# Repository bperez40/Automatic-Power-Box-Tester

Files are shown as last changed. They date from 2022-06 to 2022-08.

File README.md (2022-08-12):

# Automatic Power Box Tester
Summer 2022 ITW Vulcan Project

## Firmware Guide
 This guide assumes you're running Windows, however, you can easily do all this on other platforms, but some of the steps will vary slightly, and you probably won't be using anything with a batch script on another platform (unless you really want to).

### Cloning Repo (required)
If you don't have git installed, go ahead and download it from here: https://git-scm.com/
Then, in a command-line shell (On Windows, Command Prompt and PowerShell are installed by default), navigate to wherever you want to store the project and then run:
git clone https://github.com/bperez40/Arduino-Power-Box-Tester

The repository is layed out as follows
```
Automatic-Power-Box-Tester
├───lib
│   ├───Adafruit-GFX-Library
│   ├───Adafruit_BusIO
│   ├───Adafruit_RA8875
│   ├───iodefs
│   ├───PBTCheck
│   ├───PBTGraphics
│   └───PWM
├───main
├───tests
│   ├───ADC_test
│   └───PWM_Out
└───util
    ├───Hardware Design Files
    │   ├───AutoPowerBoxTesterv1.0
    │   │   └───GerberFiles
    │   ├───AutoPowerBoxTesterv1.1
    │   │   └───GerberFiles
    │   └───SparkWireInterfacev1.0
    │       └───GerberFiles
    ├───scripts
    └───images
```
Opening it up, you'll be on the root of the repository.
- main stores the main program
- lib has all the required external and custom libraries for the project
- tests has some basic tests mostly used for debugging and not much else
- util has images used in the readme as well as all the hardware design files for the PCBs

Go ahead and run the update.bat script. This initializes all the submodules, which have dependencies that the firmware uses. Also run this whenever you want to pull the most recent version of the firmware.

### Arduino Setup (required)
We're not quite ready to actually compile and upload firmware to the Arduino yet. We need to install a program to do so. You have a few ways to do this.

#### 1. Using Arduino CLI (recommended)
If you want to use the Arduino CLI to make your own custom configuration, start by downloading the Arduino CLI from Arduino here: https://www.arduino.cc/pro/cli

Extract it in the repository's root and rename the folder it's contained in to .arduino-cli. So, {top-of-repository}/.arduino-cli

Your new file structure will look something like this...
```
Automatic-Power-Box-Tester
├───.arduino-cli
├───lib
│   ├───Adafruit-GFX-Library
│   ├───Adafruit_BusIO
│   ├───Adafruit_RA8875
│   ├───iodefs
│   ├───PBTCheck
│   ├───PBTGraphics
│   └───PWM
├───main
├───tests
│   ├───ADC_test
│   └───PWM_Out
└───util
    ├───Hardware Design Files
    │   ├───AutoPowerBoxTesterv1.0
    │   │   └───GerberFiles
    │   ├───AutoPowerBoxTesterv1.1
    │   │   └───GerberFiles
    │   └───SparkWireInterfacev1.0
    │       └───GerberFiles
    ├───scripts
    └───images
```

The fast way to compile and upload the program is to run the CompileAndUpload.bat script in util.

If you want to compile it manually and play around the the CLI a bit, you can do the following.

To compile, run the following from your root folder:

arduino-cli.exe compile --build-path ./build --libraries ./lib -b Arduino:avr:mega main/main.ino

To compile and upload, you can instead do:

arduino-cli.exe compile --build-path ./build --libraries ./lib -b Arduino:avr:mega -p COM4 -u main/main.ino

Replacing COM4 with whatever your Arduino is actually using. You can figure that out by running:

arduino-cli.exe board list

This is also how you can figure out an Arduino's FQBN.

#### 2. Using Arduino IDE
I haven't set this up on Arduino IDE, but I imagine this is what people are more familar with when using any Arduino platform. If you do this, you'll have to manually add the libraries using the GUI and set up the board type and COM port similar to option 2. If that's done correctly, all you have to do is press the run button and it should work fine.

### Changing the lock screen password (important, but optional)
I recognize that this is incredibly insecure, but it's highly unlikely anyone who would abuse this would come looking here to do so.

To change the lockscreen password, navigate to PBTGraphics.cpp and change the line with...

int actual_passcode[4] = {#, #, #, #}; /*!! SET PASSCODE HERE !!*/

...by setting the # to whatever you want it to be, in the order you want them to be entered. Then build and upload the project to the Arduino.

### Running Python Scripts (optional)
If you don't already have it installed, install from their website: https://www.python.org/

Once Python is installed, open a terminal. 

In the repository's root folder, run python -m venv .venv
.venv is gitignored by default, but if you want to name it something else, change the gitignore to reflect whatever you call it.

VSCode should give a prompt that it has detected a new virtual environment. Confirm the prompt.

Select the proper virtual environment interpreter by opening the command pallette and selecting it using >Python: Select Interpreter

In Windows, run the activate script to use your virtual environment. You could use the
global environment instead, but that's icky:
{wherever-venv-is}\.venv\scripts\activate

If using the debugger, you might need to activate it again in the new terminal that pops up.

If you get the message "Activate.ps1" is not digitally signed, run:
Set-ExecutionPolicy -ExecutionPolicy RemoteSigned -Scope Process

Once the virtual environment is activated, install whatever packages you want using
pip install {package-name}
If you get an error running a python script, chances are you're missing a package. Read the terminal output to see what exactly the error is.

Whenever you're done working in the virtual environment, type deactivate and you'll leave the virtual environment and return to the global environment.

### Logging Arduino output data using PuTTY (optional)
If you want to log the Arduino's output data when it's connected over USB, you can do so using PuTTY (or TeraTerm, or whatever other similar program).

First, install PuTTY from here: https://www.putty.org/

Match all the proper settings in the session tab, such as COM port, baud rate, so on so forth.

In the logging tab, set session logging to "All session output." Name the file whatever you like and configure PuTTY to store putty.log or whatever you want to call it in the util folder of the repository. When you start a session, PuTTY will then create a log in the util folder. You can run the visualizer python script to then visualize the file's output. This is useful for graphing ADC data.

If you want to start PuTTY using a terminal, run the following command:

plink.exe -load {SAVED-PROFILE}

Where the saved profile is one that you've previously set up. If plink.exe isn't found, make sure it's part of your PATH environment.

## Hardware
Hardware design files and assembly instructions can be found in util/HardwareDesignFiles.\
They include the EAGLE board and schematic files, gerber files, BOM, and pick and place for each board.\
You can also view each board on AISLER with the following links.\
[Auto Power Box Tester v1.1 (redirect)](https://aisler.net/p/JCLNWTRR)\
[Spark Wire Interface Board v1.0 (redirect)](https://aisler.net/p/PQONZLWA)\
[Auto Power Box Tester v1.0 (redirect)](https://aisler.net/p/SKLRNZQZ)

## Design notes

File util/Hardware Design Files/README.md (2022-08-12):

# Hardware Guide
Originally, the power box tester was intended to be a single board to which you attach connectors to. Were it not for the 25 kV ignition, this would be possible. However, because we could not implement a part of the circuit on either the Auto Power Box Tester PCB or on the Spark Wire Interface board due to time limitations, the setup requires slightly more complexity and care.

## Auto Power Box Tester v1.1 Assembly
Setting up the Auto Power Box Tester v1.1 is very straightforward, though it does require a bit of soldering (though every part can be done with a soldering iron alone).

If you have no prior experience with soldering, here are a few guides on how to do so.

SMD soldering: https://www.sparkfun.com/tutorials/36
Through hole soldering: https://learn.sparkfun.com/tutorials/how-to-solder-through-hole-soldering/all#res
Hot air: https://learn.sparkfun.com/tutorials/how-to-use-a-hot-air-rework-station/all

Assemble the board in its entirety. Ideally, this board would be assembled by the PCB manufacturer, so for future revisions, consider getting this assembled by the manufacturer as it is more or less in a stable position. 

The connectors are also all assembled with each connection as is with the exception of the blower motor connector, which I will elaborate on later. Each of these connectors have a Mini-Fit Jr. receptacle on one end and a Mini-Fit Jr. panel mount plug on the other end.

The Spark Wire Interface board is a supplementary board to the main board. It required major adjustments after production, so this is where the complexity comes in.

First, start by assembling the required components of the spark interface board. Adjustments were made to exclude parts of the board, so you will only need to assemble:
- J1
- R3
- R4
- D1
- Quick connect tab on the holes labeled "spark wire connect"

After those are assembled, you will also need to place a jumper wire in one location, with the solder joints being circled in this image:\
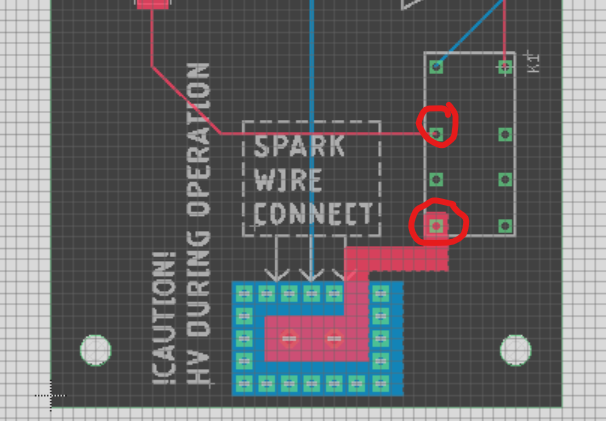
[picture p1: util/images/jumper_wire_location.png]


As a result, it will look something like this:\
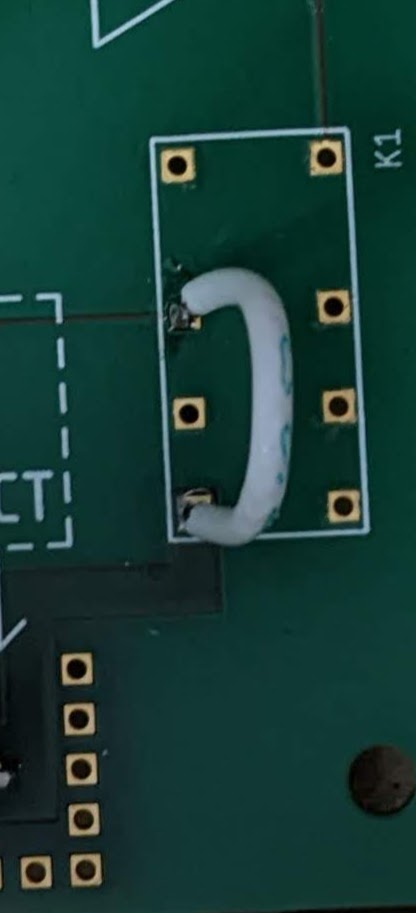
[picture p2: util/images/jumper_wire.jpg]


The idea here is we're trying to short the path that leads between the spark wire interface and the rectification circuit. Instead of that circuit being closed by a +3.3v relay (as it originally was supposed to be), it is being closed by a 120 VAC contactor. We had to change those out as the contactor could handle the higher voltage rating on its contacts (effectively, it prevented the high voltage line from arcing when in its open position due to the larger air gaps).

Now, we need to make a few connections. Terminal block for reference:\
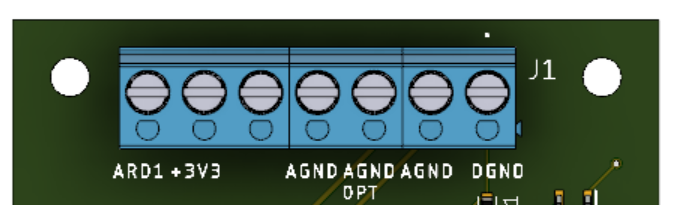
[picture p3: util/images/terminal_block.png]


Start by connecting the left most AGND to the interior of the chassis (requires a ring terminal crimp). Next, connect the right AGND to a wire nut. From that wire nut, you need to attach two more wires to two separate locations: One back to AGND OPT, and the other to one side of the contactor's coil (requires a quick connect crimp). The other side of the contactor's coil should be connected to wire 2 on the blower motor connector. That way, the contactor now has both 120 VAC and GND connected to its coil.

After the two boards are assembled properly, you'll need to make connections to the breadboard and contactor. Usually, the breadboard would be integrated onto the spark interface board, but since there wasn't enough time remaining in the internship to do so, we had to settle for this.

The breadboard is a corrected circuit of what the spark interface board should have been, and it requires the following
- NPN transistor (like the MPSA06): 1
- 270 ohm resistor: 1
- 3700 ohm resistor: 2
- [J104D2C3VDC.15S or equivalent 3.3v relay](https://www.digikey.com/en/products/detail/cit-relay-and-switch/J104D2C3VDC-15S/12502634)
- [CPC1976Y, AQY212GHAX, or something similar](https://www.digikey.com/en/products/detail/ixys-integrated-circuits-division/CPC1976Y/1277138)

Using these, you need to build the following circuit. Pay heed to the comments:\
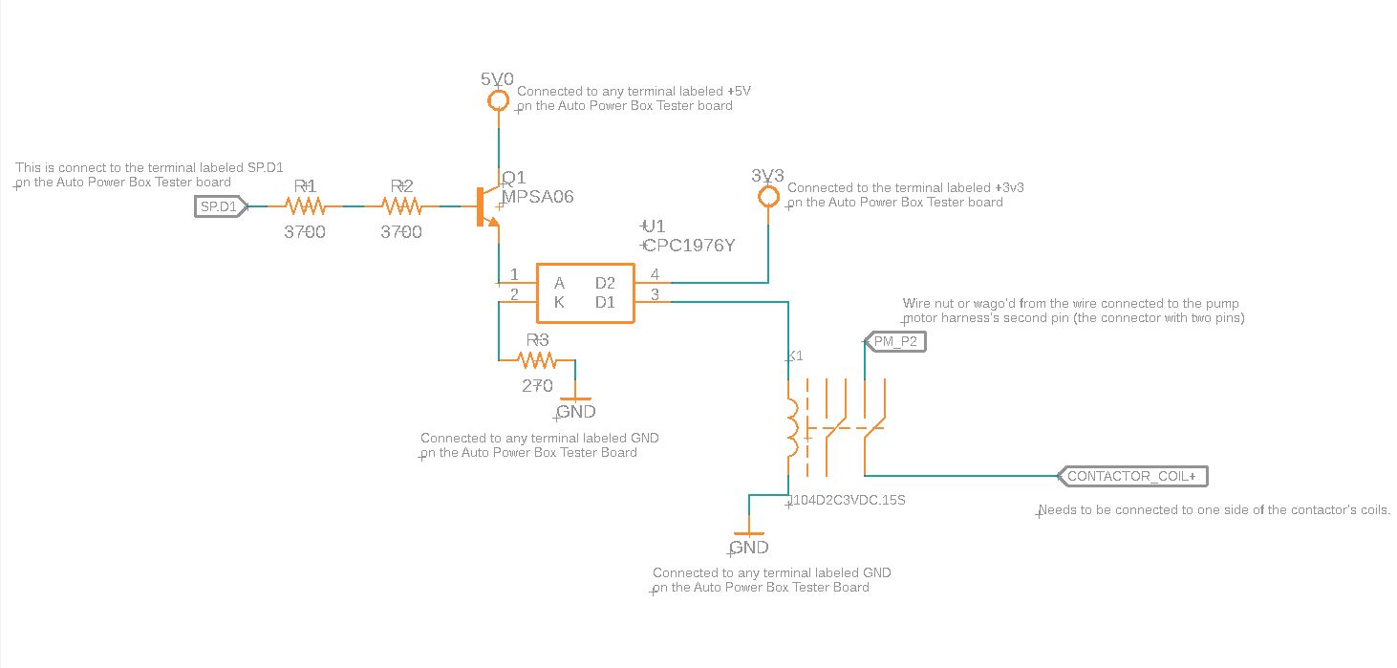
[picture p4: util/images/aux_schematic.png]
Schematic


To finish these connections, we need to connect the rest of the contactor's connections. We've already attached the necessary wires to the coil ends, but we need to set up the spark wire to connect to the terminal. One side of a terminal should by connected directly to the power box's spark wire (usually we connect the spark wire to a QC terminal on the workbench and have another wire leading into the Auto Power Box Tester's chassis, where it then connects to one of the contactor's terminal). The other side of that terminal should be connected to the quick connect labeled "SPARK WIRE CONNECT" on the spark wire interface board. After that, the device should be fully electrically assembled. You know this is done incorrectly if the device is never able to rectify the signal (no path to ground) or if there is arcing occuring between the AGND and AGND OPT traces (unequal potentials between these two signals).

Effectively, what all this was for was to allow the Arduino to be able to control when the spark wire's signal is being recitified or not. The circuit on the breadboard allows the Arduino to control a 120 VAC signal (on the pump motor connector's second wire), which in turn triggers the contactor on and off.

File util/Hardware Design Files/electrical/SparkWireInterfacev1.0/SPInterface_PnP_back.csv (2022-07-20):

R2 | 40.64 | 104.14 | 180.00 | 3300 | RESC1608X60
U2 | 49.53 | 106.68 | 90.00 | PZTA06SOT-223_ONS | SOT-223_ONS

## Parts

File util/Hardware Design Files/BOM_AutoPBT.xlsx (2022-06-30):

Description | Qty | MPN | Designator | Footprint | Additional Comments
PCB Components
1k ohm, 1/4 W, 0603, 1% | 13 | CRGP0603F1K0 | R1, R6, R8, R9, R16, R17, R18, R34, R35, R36, R37, R44, R45 | CHIP-0603(1608-METRIC)
330 ohm, 1/4 W, 0603, 1% | 7 | CRGP0603F330R | R2, R7, R10, R14, R15, R28, R33 | CHIP-0603(1608-METRIC)
3.3k ohm, 1/4 W, 0603, 1% | 7 | CRGP0603F3K3 | R3, R4, R5, R11, R12, R13, R19 | CHIP-0603(1608-METRIC)
Mini-Fit Jr. 39281023 | 1 | 39281023 | J3 | CON_39281023
Mini-Fit Jr. 39281043 | 1 | 39299046 | J6 | CON_39281043
Mini-Fit Jr. 39281063 | 2 | 39293066 | J2, J5 | CON_39281063
Mini-Fit Jr. 39281123 | 1 | 39281123 | J4 | CON_39281123
Mini-Fit Jr. 39301039 | 1 | 39301039 | J1 | CON_39301039
6.8k ohm, 1/4 W, 0603, 1% | 18 | CRGP0603F6K8 | R20, R21, R22, R23, R24, R25, R26, R27, R29, R30, R31, R32, R38, R39, R40, R41, R42, R43 | CHIP-0603(1608-METRIC)
AQY212GHAX | 6 | AQY212GHAX | U6, U7, U11, U12, U13, U18 | 4-SMD, Gull Wing
J107F1CS203VDC.80 | 1 | J107F1CS203VDC.80 | K1 | J107F1CS203VDC.80
LM1086CT-3.3/NOPB | 1 | LM1086CT-3.3/NOPB | U2 | TO-220-3
LM1086CT-5.0/NOPB | 1 | LM1086CT-5.0/NOPB | U1 | TO-220-3
PJ-202AH | 1 | PJ-202AH | J7 | PJ-202AH
TB001-500-07BE | 1 | TB001-500-07BE | J8 | TB001-500-07BE
VOL628A-3T | 12 | VOL628A-3T | U3, U4, U5, U8, U9, U10, U14, U15, U16, U17, U19, U20 | 4-SMD, Gull Wing
RA8875 DRIVER BOARD FOR 40P TFT | 1 | 1528-1861-ND | A3 | N/A | Do Not Install
ARDUINO MEGA2560 ATMEGA2560 | 1 | 1050-1018-ND | A1 | N/A | Do Not Install
SPARK/FLAME Breakout | 1 | N/A | A2 | N/A | Do Not Install
Chassis Components
SWITCH ROCKER SPST 20A 125V | 1 | RSC241D1A81 | N/A | N/A
CONN PLUG 12POS PANEL MOUNT | 1 | 39012126 | N/A | N/A
CONN PLUG 6POS PANEL MOUNT | 2 | 39012066 | N/A | N/A
CONN PLUG 4POS PANEL MOUNT | 1 | 39012046 | N/A | N/A
CONN PLUG 3POS VERT PANEL MOUNT | 1 | 39014033 | N/A | N/A
CONN PLUG 2POS PANEL MOUNT | 1 | 39012026 | N/A | N/A
Harness Components
CONN RECEPT 12POS DUAL | 1 | 39012125 | N/A | N/A
CONN RECEPT 6POS DUAL | 2 | 39012065 | N/A | N/A
CONN RECEPT 4POS DUAL | 1 | 39012046 | N/A | N/A
CONN RECEPT 3POS DUAL | 1 | 39014031 | N/A | N/A
CONN RECEPT 2POS DUAL | 1 | 39012026 | N/A | N/A
Mini-Fit Male Crimp Terminal, 18-24 | 100 | 39000040 | N/A | N/A
Mini-Fit Female Crimp Terminal, 18-24 | 100 | 39000038 | N/A | N/A
Misc Components
TFT DISPLAY - 800X480 WITH TOUCH | 1 | 2354 | N/A | N/A
Screen Protector for 7" Touch Screen | 1 | N/A | N/A | N/A | Can typically by found on Amazon. Usually made of tempered glass, such as the CDEFG Wrangler JL Touch Screen Protector. Make sure it's touch sensitive and 7" screen size
Double Sided Foam Mounting Tape | 1 | N/A | N/A | N/A | Look at Amazon, Home Depot, etc. Used for mounting the display to the chassis's front
9V DC 6A Lugged External Power Supply | 1 | 23SW-00090600-S10B-US | N/A | N/A | If bought from DigiKey, does not include US mains lead.
US 3 Pin Plug to 2 Pin IEC-C7 | 1 | N/A | N/A | N/A | US mains lead for power supply. Search for one on amazon.
MALE .250" QUICK FIT TERMINAL | 2 | 1287-R | N/A | N/A

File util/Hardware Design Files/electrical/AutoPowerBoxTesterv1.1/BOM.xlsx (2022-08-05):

Description | Qty | MPN | Designator | Footprint | Additional Comments
1k ohm, 1/4 W, 0603, 1% | 15 | CRGP0603F1K0 | R1, R6, R7, R8, R14, R15, R16, R31, R32, R33, R34, R41, R44, R49, R50 | CHIP-0603(1608-METRIC)
330 ohm, 1/4 W, 0603, 1% | 7 | CRGP0603F330R | R2, R12, R13, R29, R30, R42, R43 | CHIP-0603(1608-METRIC)
3.3k ohm, 1/4 W, 0603, 1% | 8 | CRGP0603F3K3 | R3, R4, R5, R9, R10, R11, R47, R48 | CHIP-0603(1608-METRIC)
6.8k ohm, 1/4 W, 0603, 1% | 18 | CRGP0603F6K8 | R17, R18, R19, R20, R21, R22, R23, R24, R25, R26, R27, R28, R35, R36, R37, R38, R39, R40 | CHIP-0603(1608-METRIC)
100k ohm, 2512 | 2 | RMCF2512FT100K | R45, R46 | CHIP-2512
.2uF, 0603 | 2 | 1206YC204KAT4A | C1, C2 | CHIP-0603(1608-METRIC)
Mini-Fit Jr. Vertical Header 2 Connections | 1 | 39281023 | J3 | CON_39281023
Mini-Fit Jr. Vertical Header 4 Connections | 1 | 39299046 | J6 | CON_39281043
Mini-Fit Jr. Vertical Header 6 Connections | 1 | 39293066 | J5 | CON_39281063
Mini-Fit Jr. Vertical Header 8 Connections | 1 | 39281083 | J2 | CON_39281083
Mini-Fit Jr. Vertical Header 12 Connections | 1 | 39281123 | J4 | CON_39281123
Mini-Fit Jr. Vertical Header 3 Connections | 1 | 39301039 | J1 | CON_39301039
Micro-Fit 3.0 2 Connections, vertial | 1 | 430450212 | J11 | CON_430450212
Zener Diode, 10V | 1 | BZX84B10-E3-08 | D1 | SOT95P248X115-3N
Zener Diode, 2.4V, 0.35 W, 5% | 1 | BZX84C2V4-E3-08 | D2 | SOT95P248X115-3N
SPST, 3V Relay | 1 | J107F1CS203VDC.80 | K1 | N/A
LM1086CT-3.3/NOPB | 1 | LM1086CT-3.3/NOPB | U2 | TO-220-3
LM1086CT-5.0/NOPB | 1 | LM1086CT-5.0/NOPB | U1 | TO-220-3
9V, 5A, Through Hole Barrel Jack Connector | 1 | PJ-202AH | J7 | PJ-202AH
Terminal Block, 7 Connections, Flathead Screws | 3 | TB001-500-07BE | J8, J9, J10 | TB001-500-07BE
AQY212GHAX | 6 | AQY212GHAX | U8, U9, U19, U20, U25, U26 | SOP254P962X315-4N
TRANS NPN 80V 0.5A SOT223-4 | 8 | PZTA06 | U6, U7, U13, U14, U21, U22, U27, U28 | TO-261-4
Optocoupler, Phototransistor Output, AC/DC Input, Low Input Current | 14 | VOL628A-3T | U3, U4, U5, U10, U11, U12, U15, U16, U17, U18, U23, U24, U29, U30 | SOIC254P1020X230-4N
RA8875 DRIVER BOARD FOR 40P TFT | 1 | 1528-1861-ND | A2 | N/A | Do Not Install
ARDUINO MEGA2560 ATMEGA2560 | 1 | 1050-1018-ND | A1 | N/A | Do Not Install

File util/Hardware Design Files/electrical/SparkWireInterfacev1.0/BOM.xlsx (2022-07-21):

Description | Qty | MPN | Designator | Footprint | Additional Comments
3.3k ohm, 1/4 W, 0603, 1% | 1 |  | R2 | CHIP-0603(1608-METRIC)
330 ohm, 1/4 W, 0603, 1% | 1 |  | R1 | CHIP-0603(1608-METRIC)
1N4148W | 1 | 1N4148W | D1 | SOD3715X135
10M, 2512 | 2 | 352210MJT | R3, R4 | CHIP-2512
Relay DPDT, 3V | 1 | J104D2C3VDC.15S | K1 | J104D2C3VDC.15S
NPN Transistor, SMD package | 1 | PZTA06 | U2 | SOT-223_ONS
Terminal Block, 7 connections, flathead screws | 1 | TB001-500-07BE | J1 | CUI_TB001-500-07BE
Solid State Relay, DC input, AC/DC output | 1 | AQY212GHAX | U1 | SOP254P962X315-4N
Quick Fit Terminal, Male .250" | 1 | 1287-R | N/A | N/A

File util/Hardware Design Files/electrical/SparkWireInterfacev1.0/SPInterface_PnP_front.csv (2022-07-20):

D1 | 11.43 | 97.79 | 270.00 | 1N4148W | SOD3715X135
R1 | 41.91 | 110.49 | 270.00 | 330 | RESC1608X60
R3 | 11.43 | 46.99 | 90.00 | 10M | RESC6332X71
R4 | 11.43 | 72.39 | 90.00 | 10M | RESC6332X71
U1 | 49.53 | 106.68 | 270.00 | AQY212GHAX | SOP254P962X315-4N

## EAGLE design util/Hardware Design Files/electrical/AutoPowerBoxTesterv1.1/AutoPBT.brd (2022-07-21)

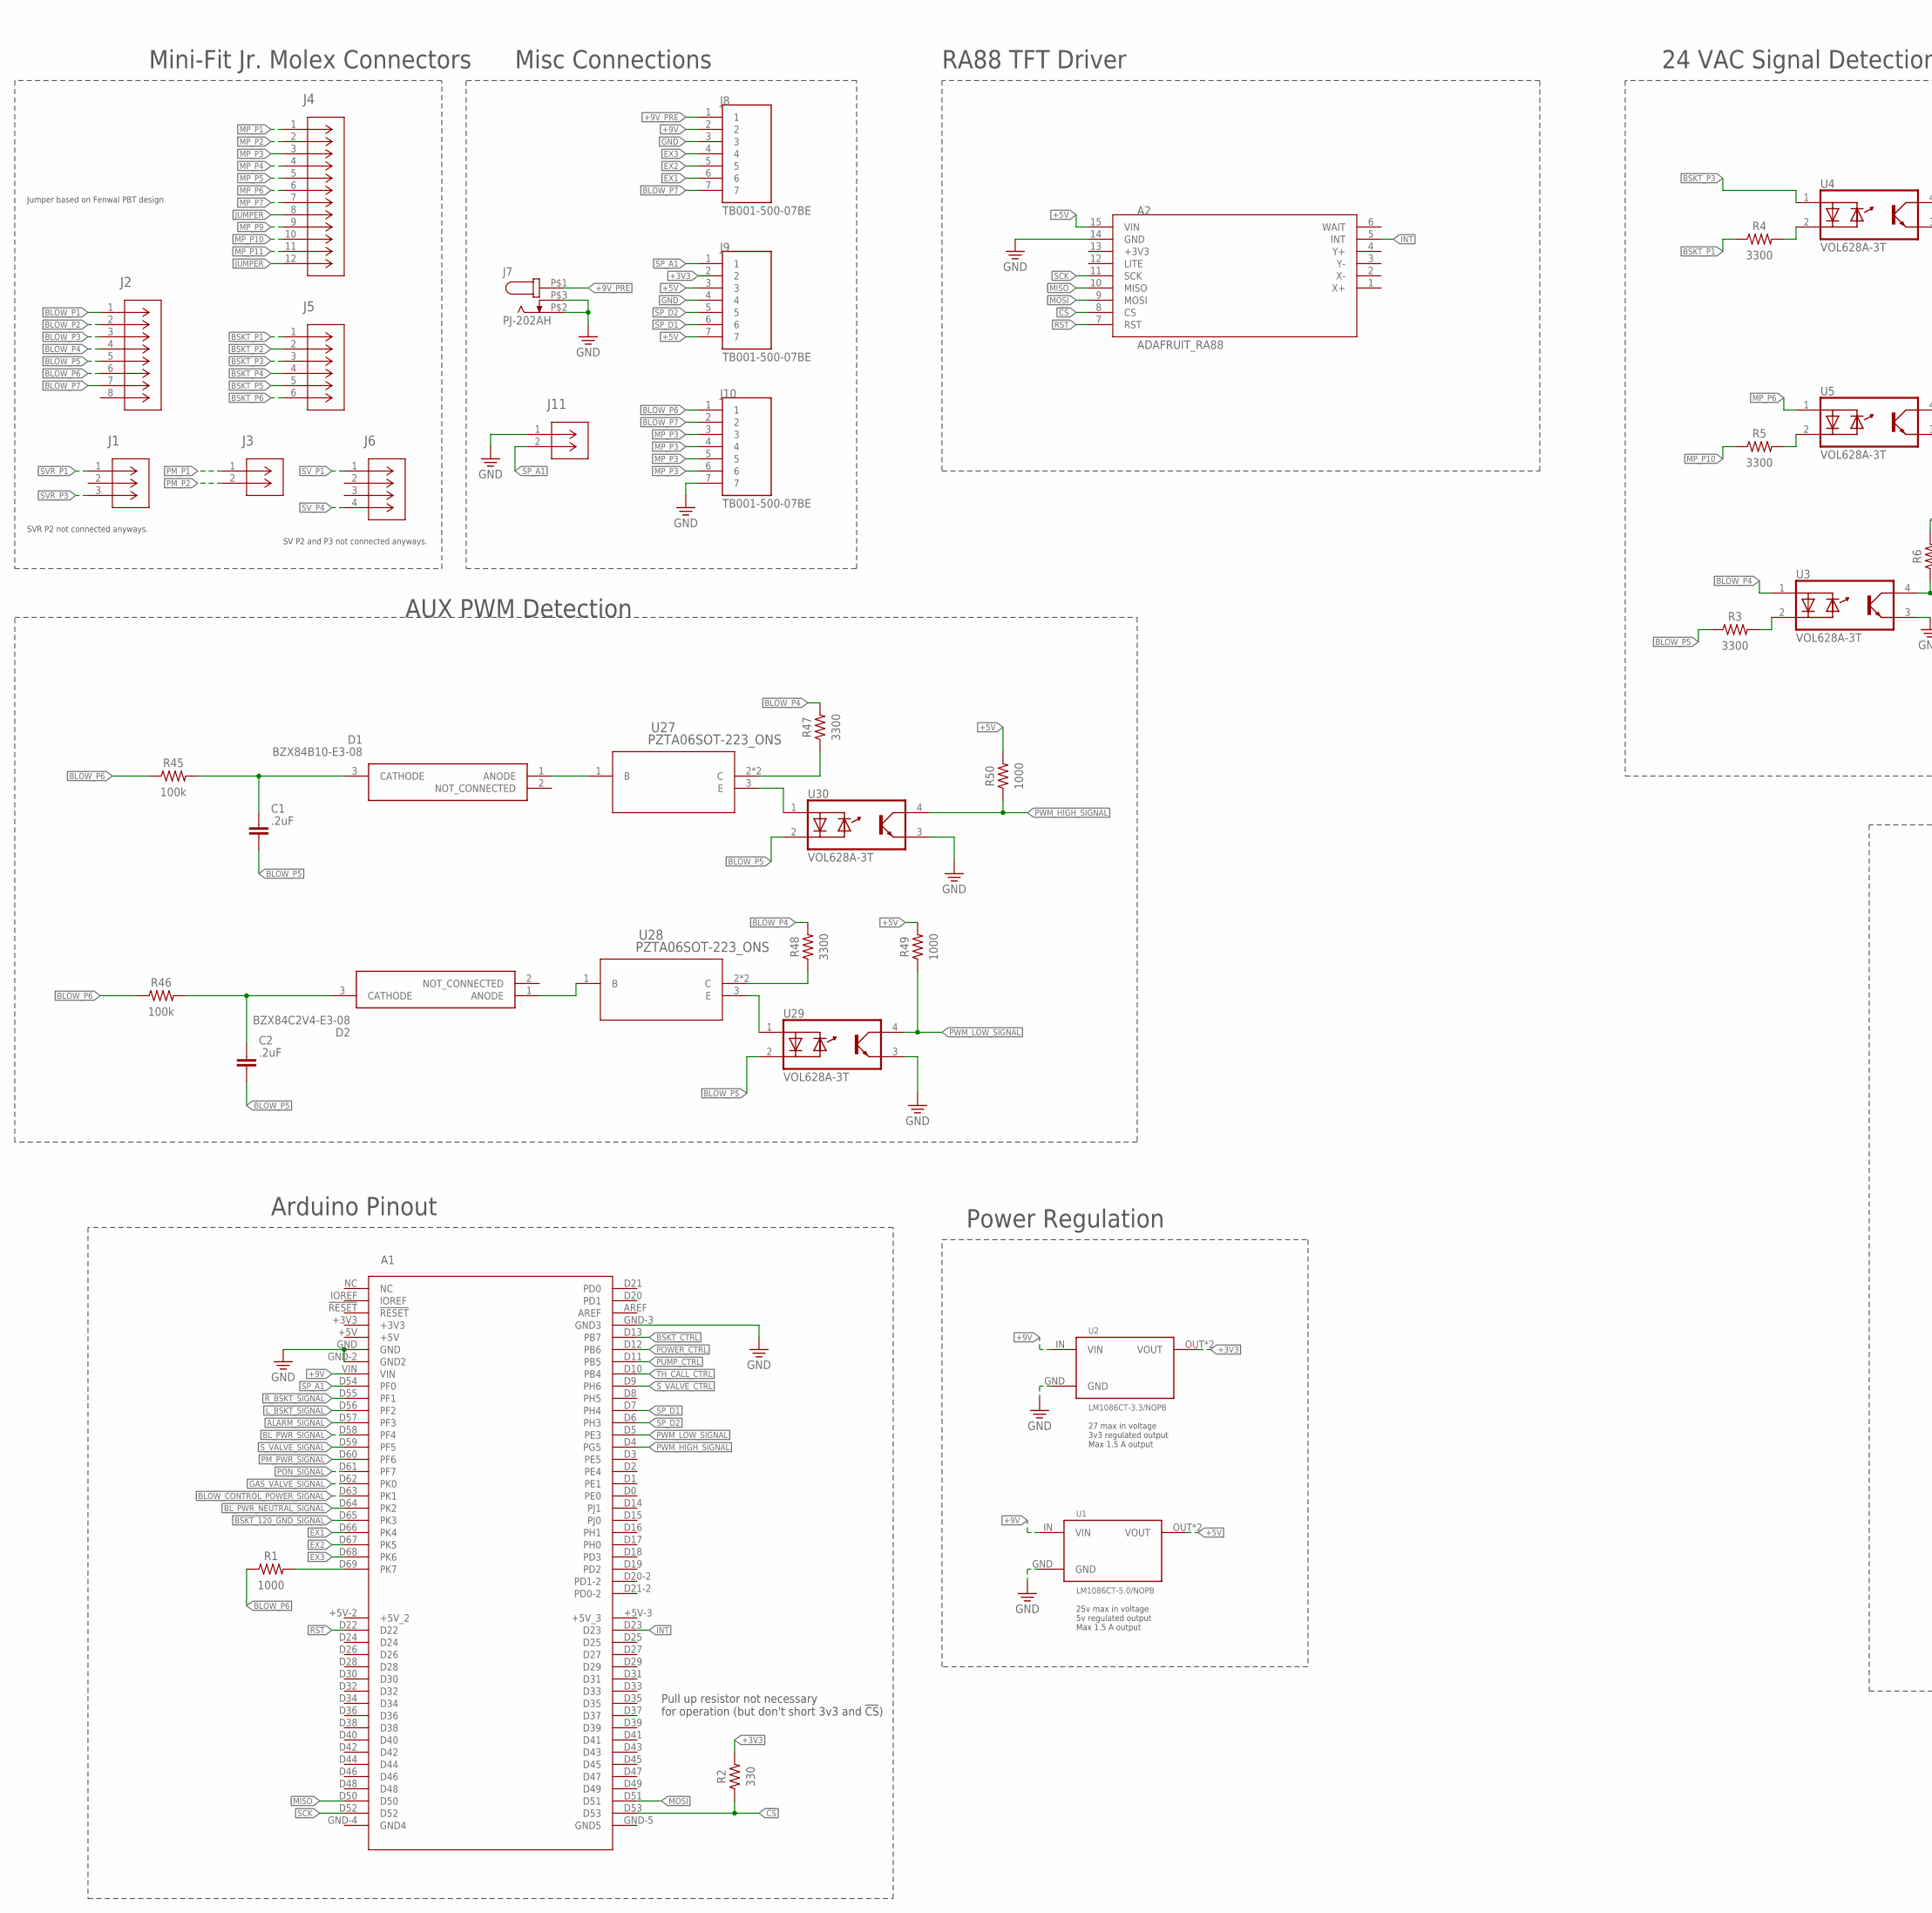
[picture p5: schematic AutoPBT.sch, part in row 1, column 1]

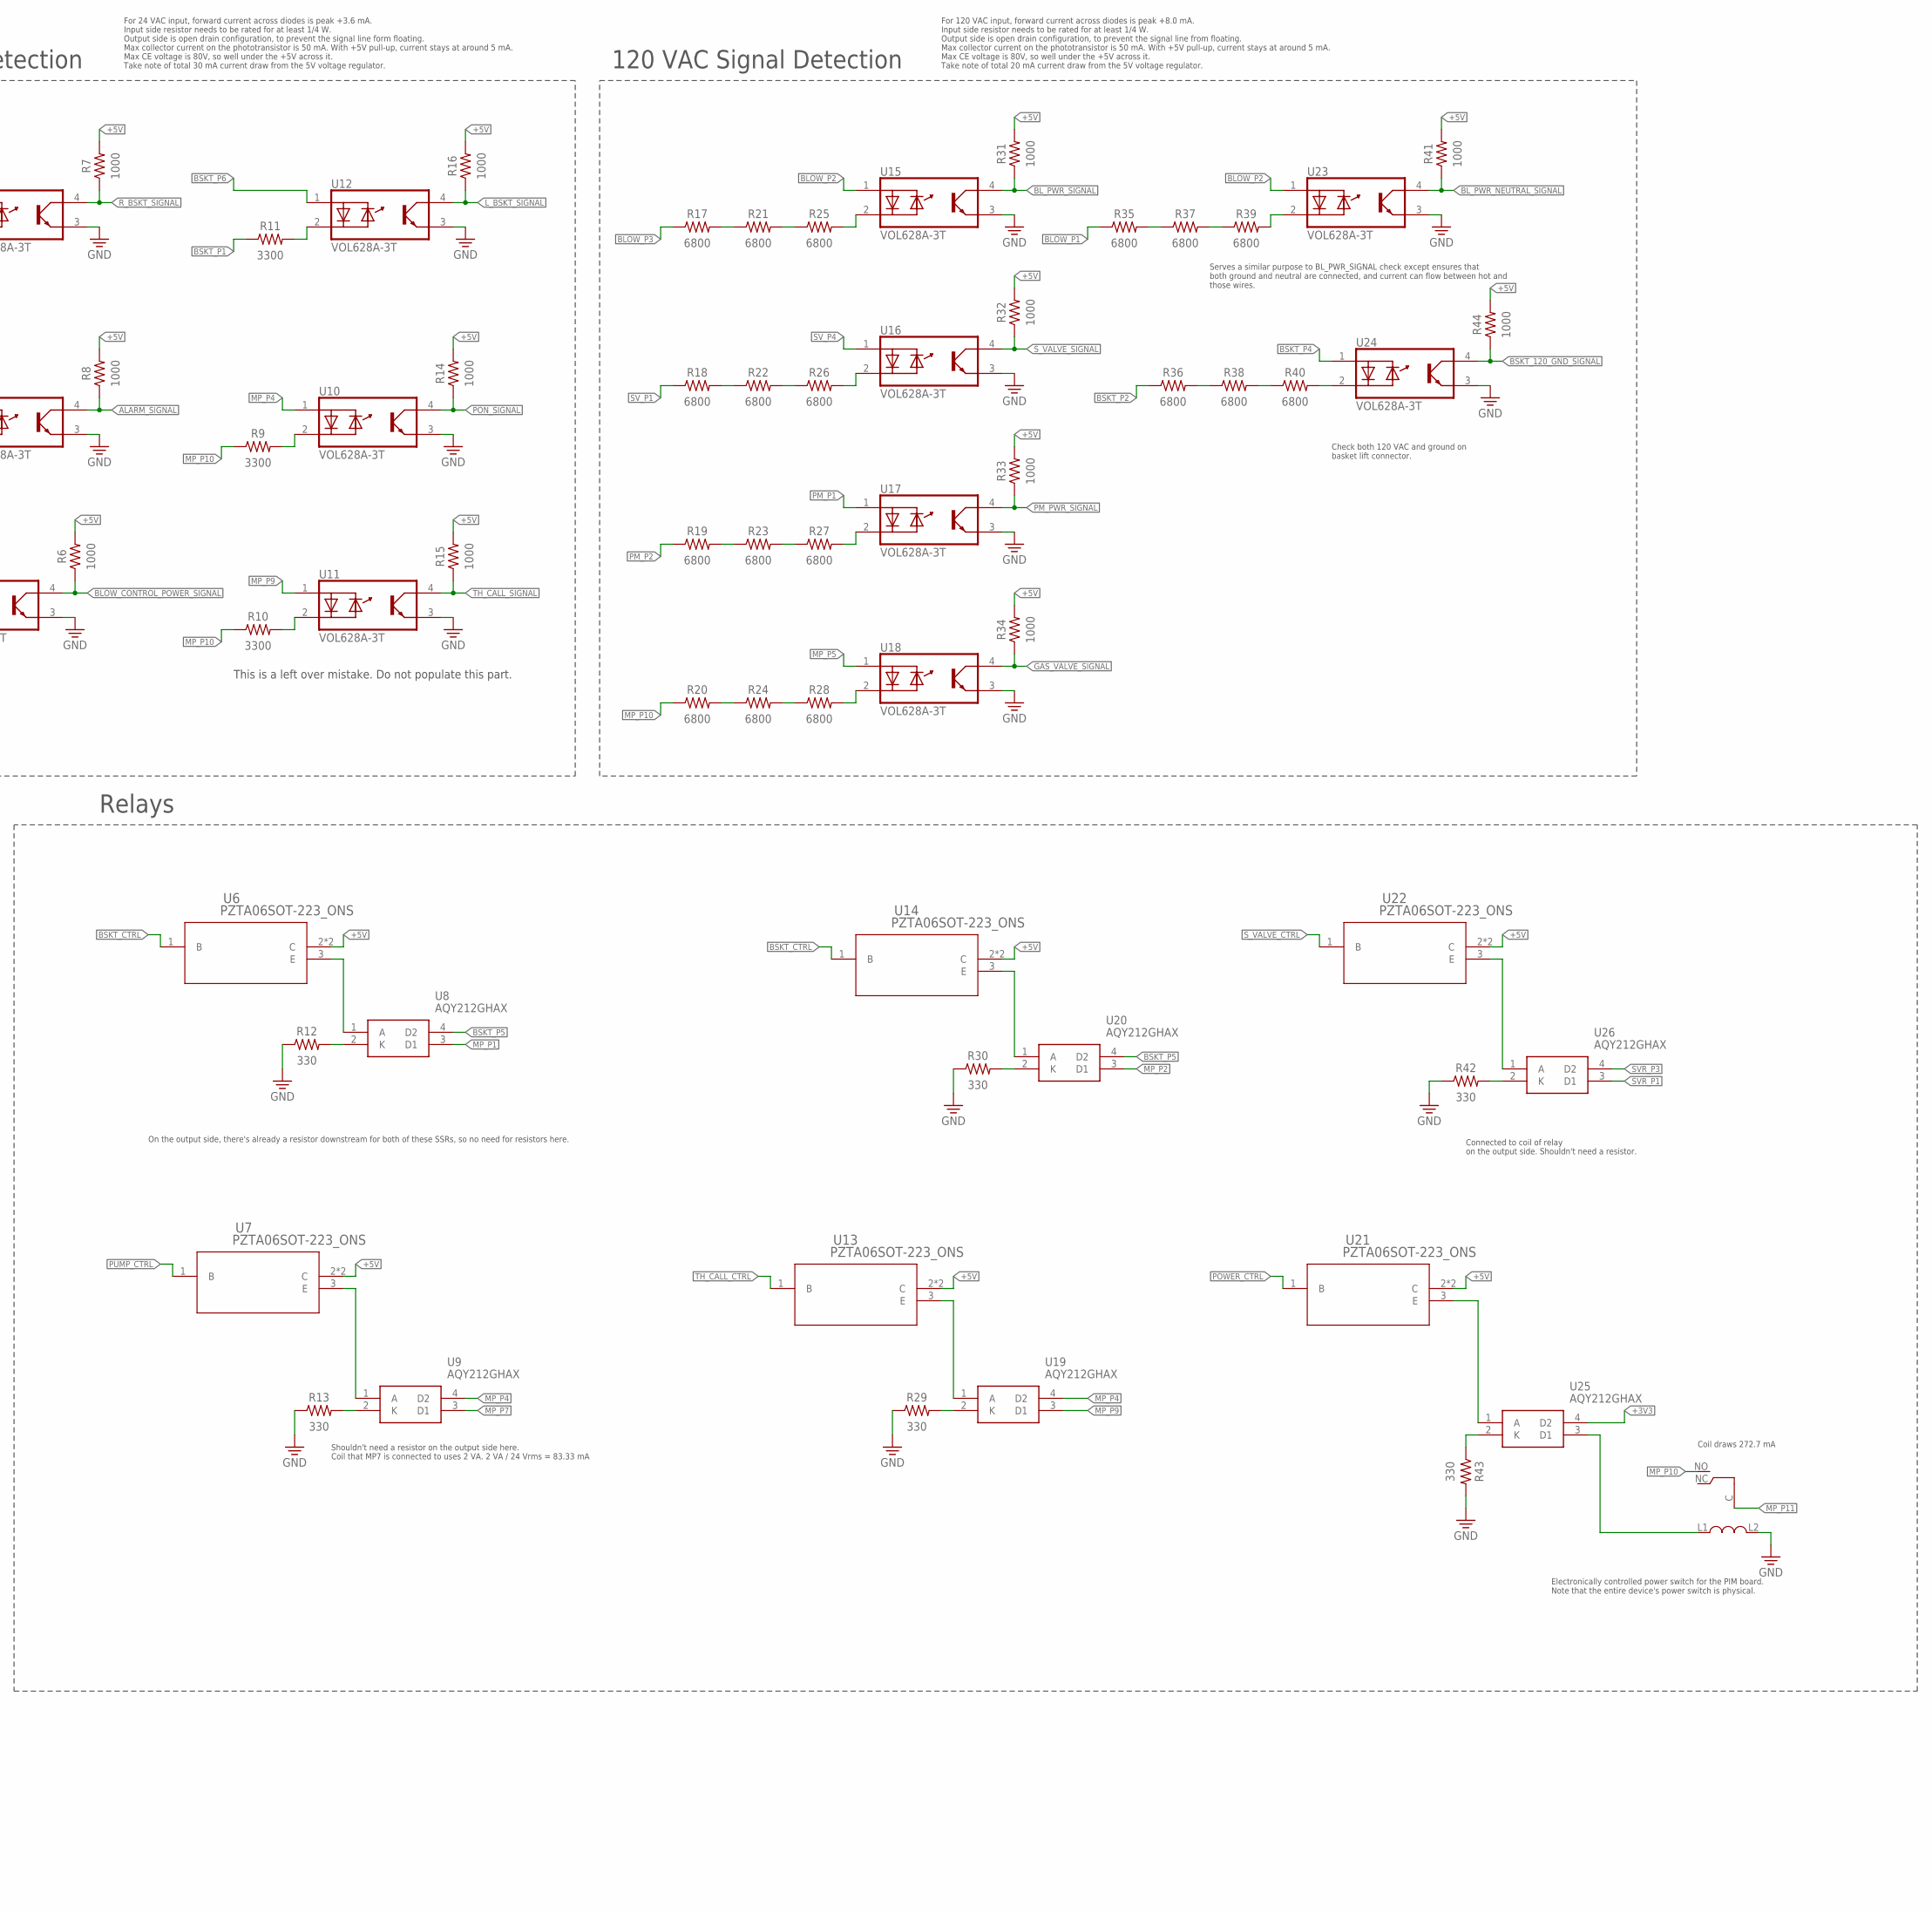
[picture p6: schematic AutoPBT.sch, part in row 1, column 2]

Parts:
A1: ARDUINO2560ARDUINO2560ACTUAL; ARDUINO2560PINS
A2: ADAFRUIT_RA88; RA88
C1, C2: .2uF; CAPC3216X135
D1: BZX84B10-E3-08; SOT95P248X115-3N
D2: BZX84C2V4-E3-08; SOT95P248X115-3N
J1: 39301039CON_39301039; CON_39301039
J2: 39281083CON_39281083; CON_39281083
J3: 39281023CON_39281023; CON_39281023
J4: 39281123CON_39281123; CON_39281123
J5: 39281063CON_39281063; CON_39281063
J6: 39299046CON_39299046; CON_39299046
J7: PJ-202AH; CUI_PJ-202AH
J8, J9, J10: TB001-500-07BE; CUI_TB001-500-07BE
J11: 430450212CON_430450212_MOL; CON_430450212_MOL
K1: J107F1CS203VDC.80
R1, R6, R7, R8, R14, R15, R16, R31, R32, R33, R34, R41, R44, R49, R50: 1000; RESC1608X60
R2, R12, R13, R29, R30, R42, R43: 330; RESC1608X60
R3, R4, R5, R9, R10, R11, R47, R48: 3300; RESC1608X60
R17, R18, R19, R20, R21, R22, R23, R24, R25, R26, R27, R28, R35, R36, R37, R38, R39, R40: 6800; RESC1608X60
R45, R46: 100k; RESC6332X71
U1: LM1086CT-5.0/NOPB; LM1086CT-3.3/NOPB
U2: LM1086CT-3.3/NOPB
U3, U4, U5, U10, U11, U12, U15, U16, U17, U18, U23, U24, U29, U30: VOL628A-3T; SOIC254P1020X230-4N
U6, U7, U13, U14, U21, U22, U27, U28: PZTA06SOT-223_ONS; SOT-223_ONS
U8, U9, U19, U20, U25, U26: AQY212GHAX; SOP254P962X315-4N

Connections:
!CS!: A1.D53, A2.8 (CS), R2.1
+3V3: J9.2, R2.2, U2.OUT (VOUT), U2.OUT2 (VOUT), U25.4 (D2)
+5V: A2.15 (VIN), J9.3, J9.7, R6.2, R7.2, R8.2, R14.2, R15.2, R16.2, R31.2, R32.2, R33.2, R34.2, R41.2, R44.2, R49.2, R50.2, U1.OUT (VOUT), U1.OUT2 (VOUT), U6.2 (C), U6.4 (C), U7.2 (C), U7.4 (C), U13.2 (C), U13.4 (C), U14.2 (C), U14.4 (C), U21.2 (C), U21.4 (C), U22.2 (C), U22.4 (C)
+9V: A1.VIN, J8.2, U1.IN (VIN), U2.IN (VIN)
+9V_PRE: J7.P$1 (1), J8.1
ALARM_SIGNAL: A1.D57 (PF3), R8.1, U5.4 (CO)
BLOW_CONTROL_POWER_SIGNAL: A1.D63 (PK1), R6.1, U3.4 (CO)
BLOW_P1: J2.1, R35.1
BLOW_P2: J2.2, U15.1 (A/C), U23.1 (A/C)
BLOW_P3: J2.3, R17.1
BLOW_P4: J2.4, R47.2, R48.2, U3.1 (A/C)
BLOW_P5: C1.2, C2.2, J2.5, R3.1, U29.2 (C/A), U30.2 (C/A)
BLOW_P6: J2.6, J10.1, R1.1, R45.1, R46.1
BLOW_P7: J2.7, J8.7, J10.2
BL_PWR_NEUTRAL_SIGNAL: A1.D64 (PK2), R41.1, U23.4 (CO)
BL_PWR_SIGNAL: A1.D58 (PF4), R31.1, U15.4 (CO)
BSKT_120_GND_SIGNAL: A1.D65 (PK3), R44.1, U24.4 (CO)
BSKT_CTRL: A1.D13 (PB7), U6.1 (B), U14.1 (B)
BSKT_P1: J5.1, R4.1, R11.1
BSKT_P2: J5.2, R36.1
BSKT_P3: J5.3, U4.1 (A/C)
BSKT_P4: J5.4, U24.1 (A/C)
BSKT_P5: J5.5, U8.4 (D2), U20.4 (D2)
BSKT_P6: J5.6, U12.1 (A/C)
EX1: A1.D66 (PK4), J8.6
EX2: A1.D67 (PK5), J8.5
EX3: A1.D68 (PK6), J8.4
GAS_VALVE_SIGNAL: A1.D62 (PK0), R34.1, U18.4 (CO)
GND: A1.GND, A1.GND-2 (GND2), A1.GND-3 (GND3), A2.14 (GND), J7.P$2 (2), J7.P$3 (3), J8.3, J9.4, J10.7, J11.1, K1.L2 (5), R12.1, R13.1, R29.1, R30.1, R42.1, R43.2, U1.GND, U2.GND, U3.3 (E), U4.3 (E), U5.3 (E), U10.3 (E), U11.3 (E), U12.3 (E), U15.3 (E), U16.3 (E), U17.3 (E), U18.3 (E), U23.3 (E), U24.3 (E), U29.3 (E), U30.3 (E)
INT: A1.D23, A2.5 (INT)
JUMPER: J4.8, J4.12
L_BSKT_SIGNAL: A1.D56 (PF2), R16.1, U12.4 (CO)
MISO: A1.D50, A2.10 (MISO)
MOSI: A1.D51, A2.9 (MOSI)
MP_P1: J4.1, U8.3 (D1)
MP_P2: J4.2, U20.3 (D1)
MP_P3: J4.3, J10.3, J10.4, J10.5, J10.6
MP_P4: J4.4, U9.4 (D2), U10.1 (A/C), U19.4 (D2)
MP_P5: J4.5, U18.1 (A/C)
MP_P6: J4.6, U5.1 (A/C)
MP_P7: J4.7, U9.3 (D1)
MP_P9: J4.9, U11.1 (A/C), U19.3 (D1)
MP_P10: J4.10, K1.NO (1), R5.1, R9.1, R10.1, R20.1
MP_P11: J4.11, K1.C (3)
unnamed: R30.2, U20.2 (K)
unnamed: R29.2, U19.2 (K)
unnamed: R13.2, U9.2 (K)
unnamed: U6.3 (E), U8.1 (A)
unnamed: R42.2, U26.2 (K)
unnamed: R43.1, U25.2 (K)
unnamed: U14.3 (E), U20.1 (A)
unnamed: R39.2, U23.2 (C/A)
unnamed: R37.2, R39.1
unnamed: R35.2, R37.1
unnamed: R40.2, U24.2 (C/A)
unnamed: R38.2, R40.1
unnamed: R36.2, R38.1
unnamed: U22.3 (E), U26.1 (A)
unnamed: U7.3 (E), U9.1 (A)
unnamed: R9.2, U10.2 (C/A)
unnamed: U13.3 (E), U19.1 (A)
unnamed: U21.3 (E), U25.1 (A)
unnamed: R11.2, U12.2 (C/A)
unnamed: C2.1, D2.3 (CATHODE), R46.2
unnamed: R3.2, U3.2 (C/A)
unnamed: R4.2, U4.2 (C/A)
unnamed: D2.1 (ANODE), U28.1 (B)
unnamed: R10.2, U11.2 (C/A)
unnamed: R5.2, U5.2 (C/A)
unnamed: A1.D69 (PK7), R1.2
unnamed: R25.2, U15.2 (C/A)
unnamed: R21.2, R25.1
unnamed: R17.2, R21.1
unnamed: R26.2, U16.2 (C/A)
unnamed: R22.2, R26.1
unnamed: R18.2, R22.1
unnamed: R27.2, U17.2 (C/A)
unnamed: R23.2, R27.1
unnamed: R19.2, R23.1
unnamed: R28.2, U18.2 (C/A)
unnamed: R24.2, R28.1
unnamed: R20.2, R24.1
unnamed: R12.2, U8.2 (K)
unnamed: D1.1 (ANODE), U27.1 (B)
unnamed: C1.1, D1.3 (CATHODE), R45.2
unnamed: U28.3 (E), U29.1 (A/C)
unnamed: U27.3 (E), U30.1 (A/C)
unnamed: R47.1, U27.2 (C), U27.4 (C)
unnamed: R48.1, U28.2 (C), U28.4 (C)
PM_P1: J3.1, U17.1 (A/C)
PM_P2: J3.2, R19.1
PM_PWR_SIGNAL: A1.D60 (PF6), R33.1, U17.4 (CO)
PON_SIGNAL: A1.D61 (PF7), R14.1, U10.4 (CO)
POWER_CTRL: A1.D12 (PB6), U21.1 (B)
PUMP_CTRL: A1.D11 (PB5), U7.1 (B)
PWM_HIGH_SIGNAL: A1.D4 (PG5), R50.1, U30.4 (CO)
PWM_LOW_SIGNAL: A1.D5 (PE3), R49.1, U29.4 (CO)
RELAY_POW: K1.L1 (4), U25.3 (D1)
RST: A1.D22, A2.7 (RST)
R_BSKT_SIGNAL: A1.D55 (PF1), R7.1, U4.4 (CO)
SCK: A1.D52, A2.11 (SCK)
SP_A1: A1.D54 (PF0), J9.1, J11.2
SP_D1: A1.D7 (PH4), J9.6
SP_D2: A1.D6 (PH3), J9.5
SVR_P1: J1.1, U26.3 (D1)
SVR_P3: J1.3, U26.4 (D2)
SV_P1: J6.1, R18.1
SV_P4: J6.4, U16.1 (A/C)
S_VALVE_CTRL: A1.D9 (PH6), U22.1 (B)
S_VALVE_SIGNAL: A1.D59 (PF5), R32.1, U16.4 (CO)
TH_CALL_CTRL: A1.D10 (PB4), U13.1 (B)
TH_CALL_SIGNAL: R15.1, U11.4 (CO)

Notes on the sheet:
Mini-Fit Jr. Molex Connectors
Relays
Misc Connections
120 VAC Signal Detection
24 VAC Signal Detection
RA88 TFT Driver
For 24 VAC input, forward current across diodes is peak +3.6 mA. Input side resistor needs to be rated for at least 1/4 W. Output side is open drain configuration, to prevent the signal line form floating. Max collector current on the phototransistor is 50 mA. With +5V pull-up, current stays at aro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
For 120 VAC input, forward current across diodes is peak +8.0 mA. Input side resistor needs to be rated for at least 1/4 W. Output side is open drain configuration, to prevent the signal line from floating. Max collector current on the phototransistor is 50 mA. With +5V pull-up, current stays at ar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
On the output side, there's already a resistor downstream for both of these SSRs, so no need for resistors here.
Shouldn't need a resistor on the output side here. Coil that MP7 is connected to uses 2 VA. 2 VA / 24 Vrms = 83.33 mA
Connected to coil of relay on the output side. Shouldn't need a resistor.
Coil draws 272.7 mA
Arduino Pinout
Power Regulation
27 max in voltage 3v3 regulated output Max 1.5 A output
25v max in voltage 5v regulated output Max 1.5 A output
Electronically controlled power switch for the PIM board. Note that the entire device's power switch is physical.
SVR P2 not connected anyways.
SV P2 and P3 not connected anyways.
Serves a similar purpose to BL_PWR_SIGNAL check except ensures that both ground and neutral are connected, and current can flow between hot and those wires.
Check both 120 VAC and ground on basket lift connector.
Jumper based on Fenwal PBT design
This is a left over mistake. Do not populate this part.
Pull up resistor not necessary for operation (but don't short 3v3 and !CS!)
AUX PWM Detection

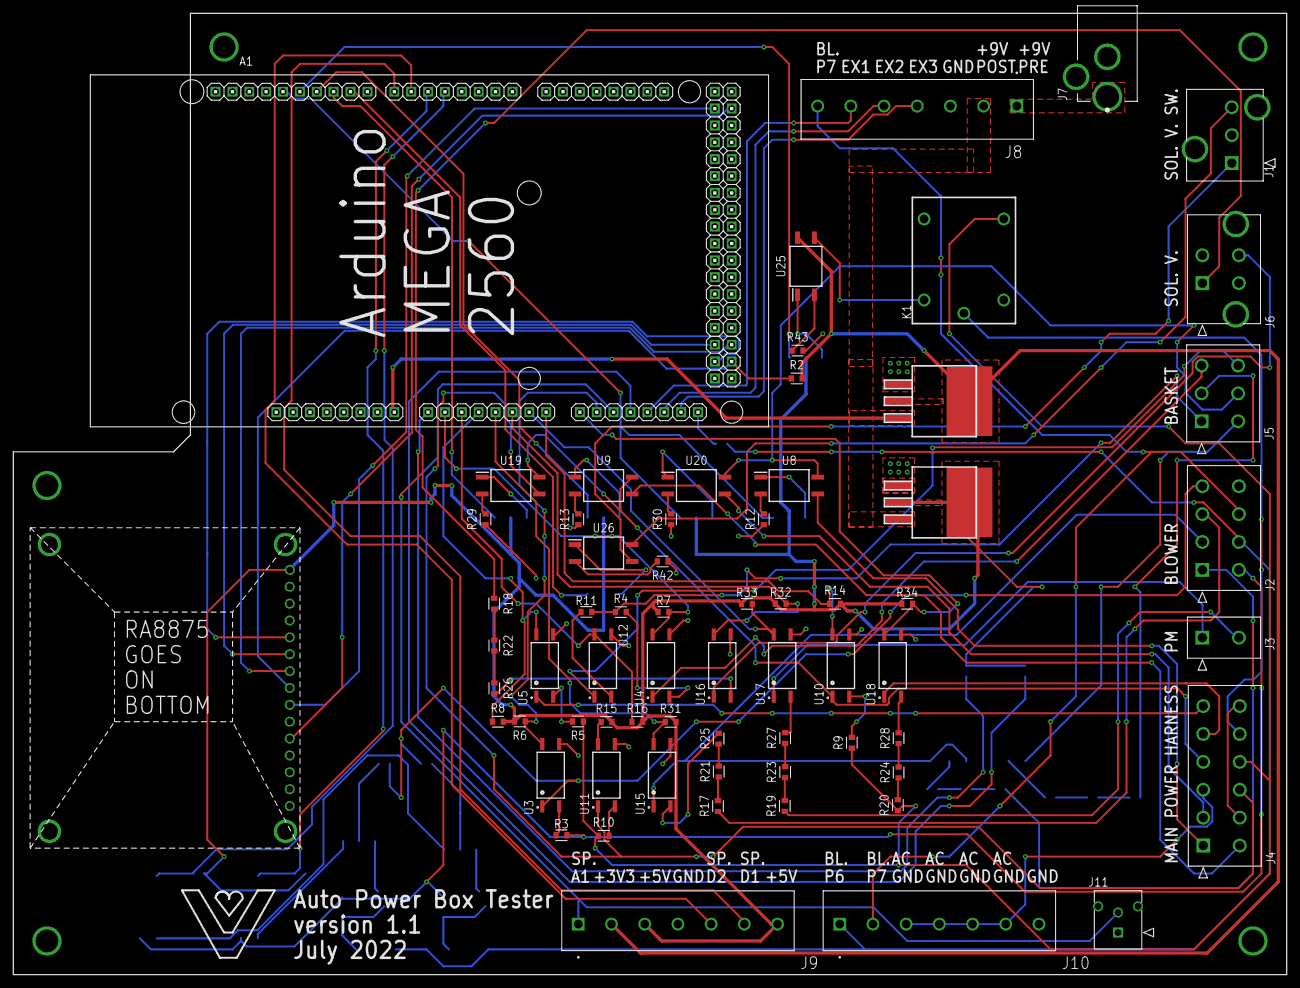
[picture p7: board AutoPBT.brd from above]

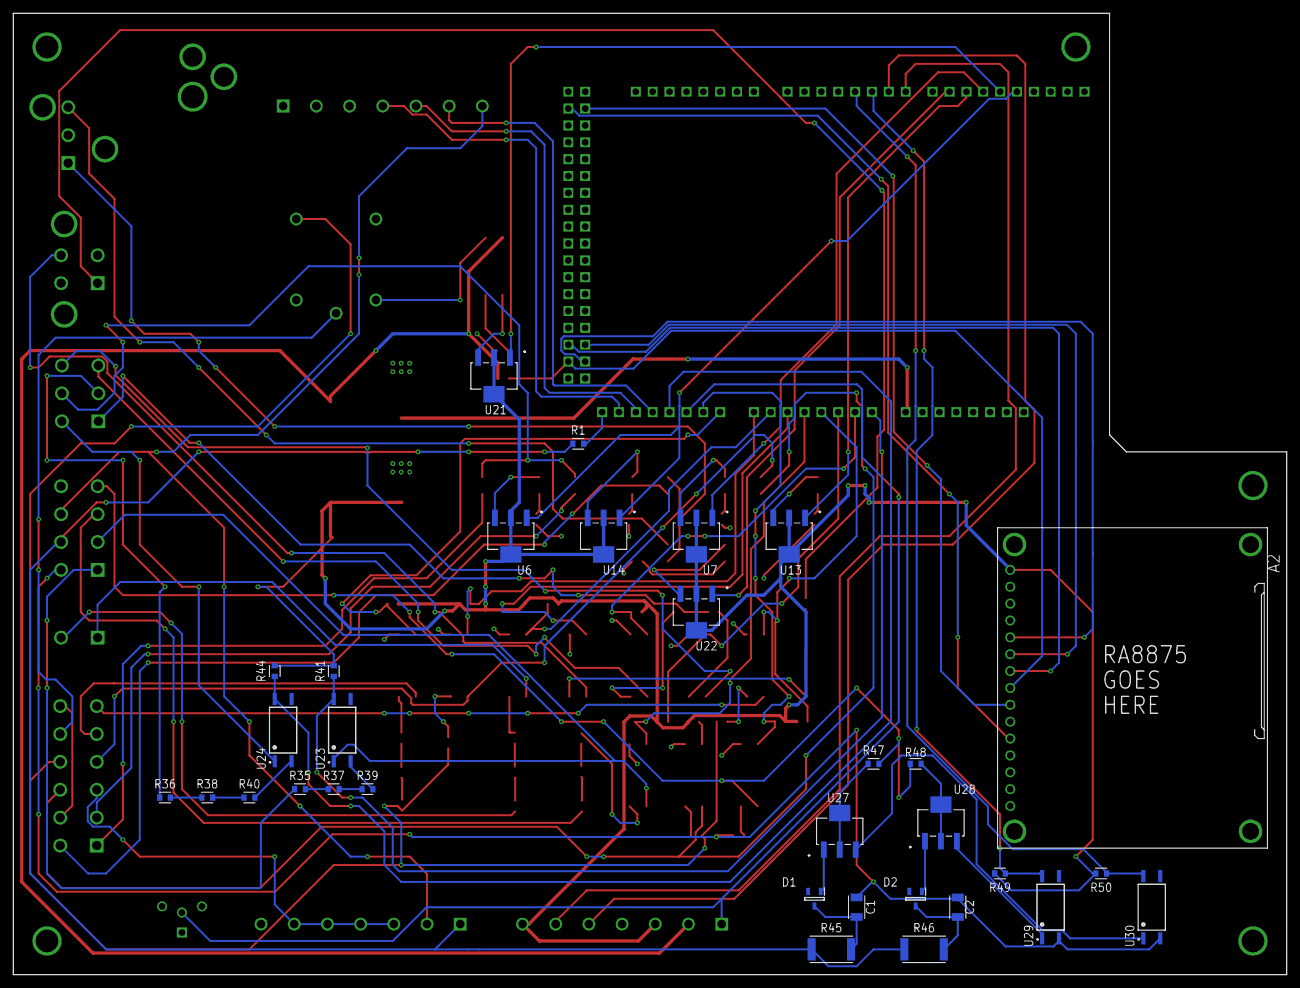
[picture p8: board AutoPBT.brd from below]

Board: 2 copper layers, 191.8 x 144.8 mm, 98 parts (32 on the bottom side), 112 nets.

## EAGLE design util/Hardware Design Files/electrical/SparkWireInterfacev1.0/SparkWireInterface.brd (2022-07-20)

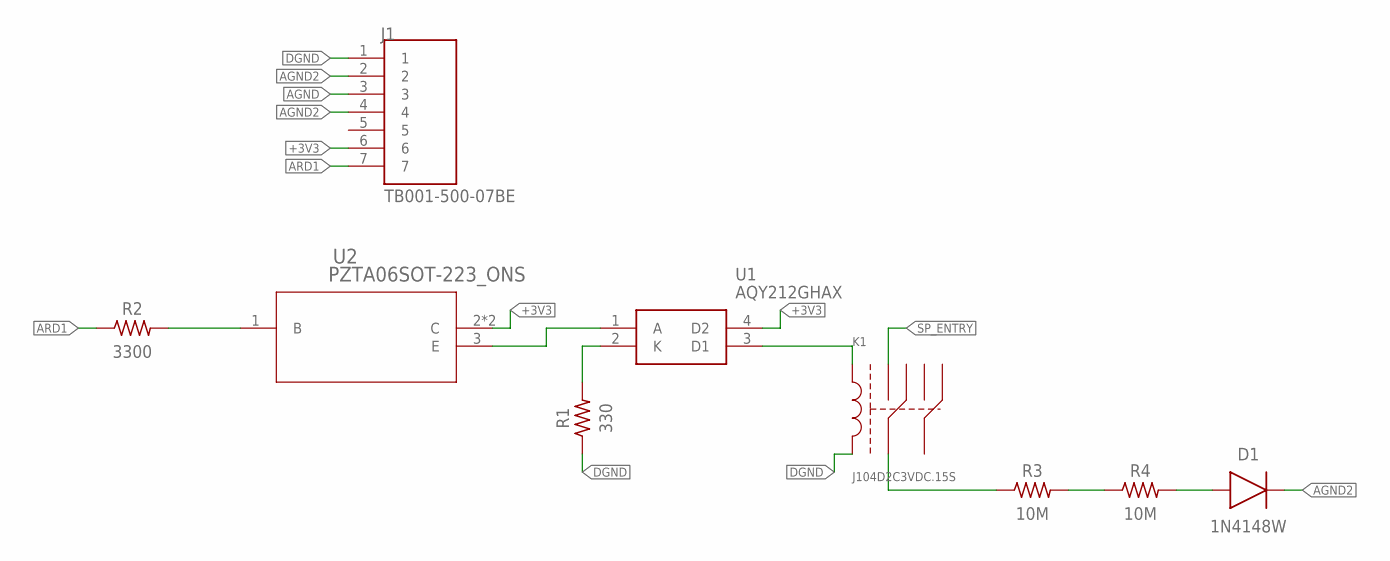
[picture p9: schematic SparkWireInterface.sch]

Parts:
D1: 1N4148W; SOD3715X135
J1: TB001-500-07BE; CUI_TB001-500-07BE
K1: J104D2C3VDC.15S
R1: 330; RESC1608X60
R2: 3300; RESC1608X60
R3, R4: 10M; RESC6332X71
U1: AQY212GHAX; SOP254P962X315-4N
U2: PZTA06SOT-223_ONS; SOT-223_ONS

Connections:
+3V3: J1.6, U1.4 (D2), U2.2 (C), U2.4 (C)
AGND: J1.3
AGND2: D1.1 (C), J1.2, J1.4
ARD1: J1.7, R2.1
DGND: J1.1, K1.1 (LA), R1.1
unnamed: K1.2 (LB), U1.3 (D1)
unnamed: U1.1 (A), U2.3 (E)
unnamed: R1.2, U1.2 (K)
unnamed: R2.2, U2.1 (B)
unnamed: K1.3 (C1), R3.1
unnamed: R3.2, R4.1
unnamed: D1.2 (A), R4.2
SP_ENTRY: K1.7 (NO1)

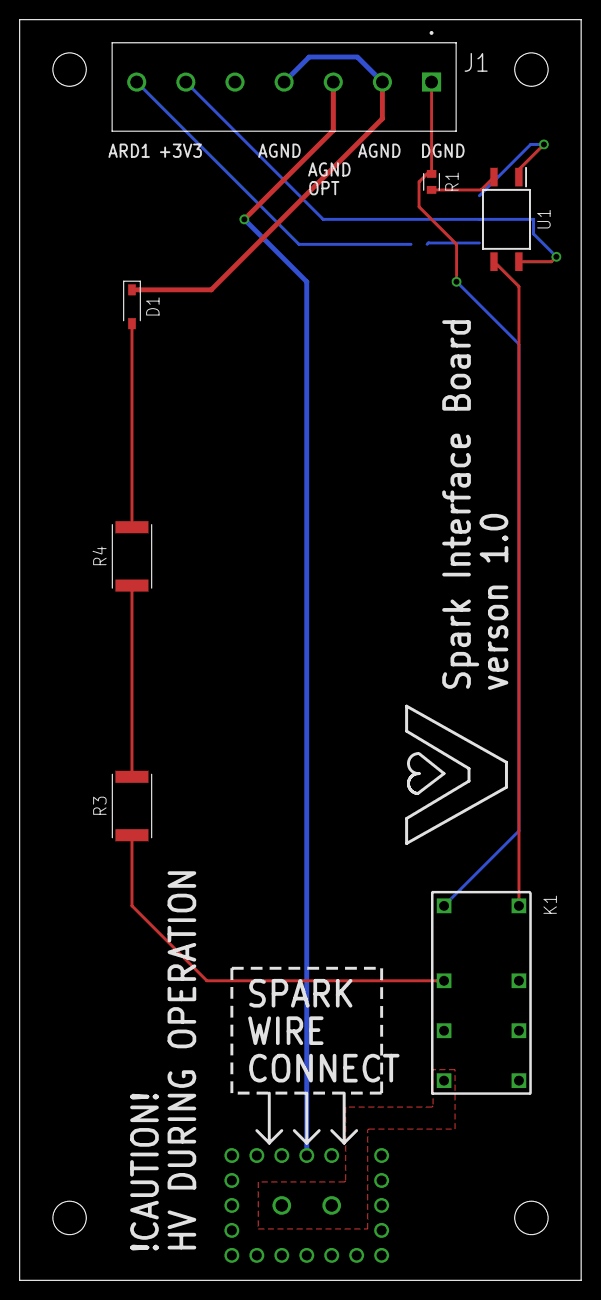
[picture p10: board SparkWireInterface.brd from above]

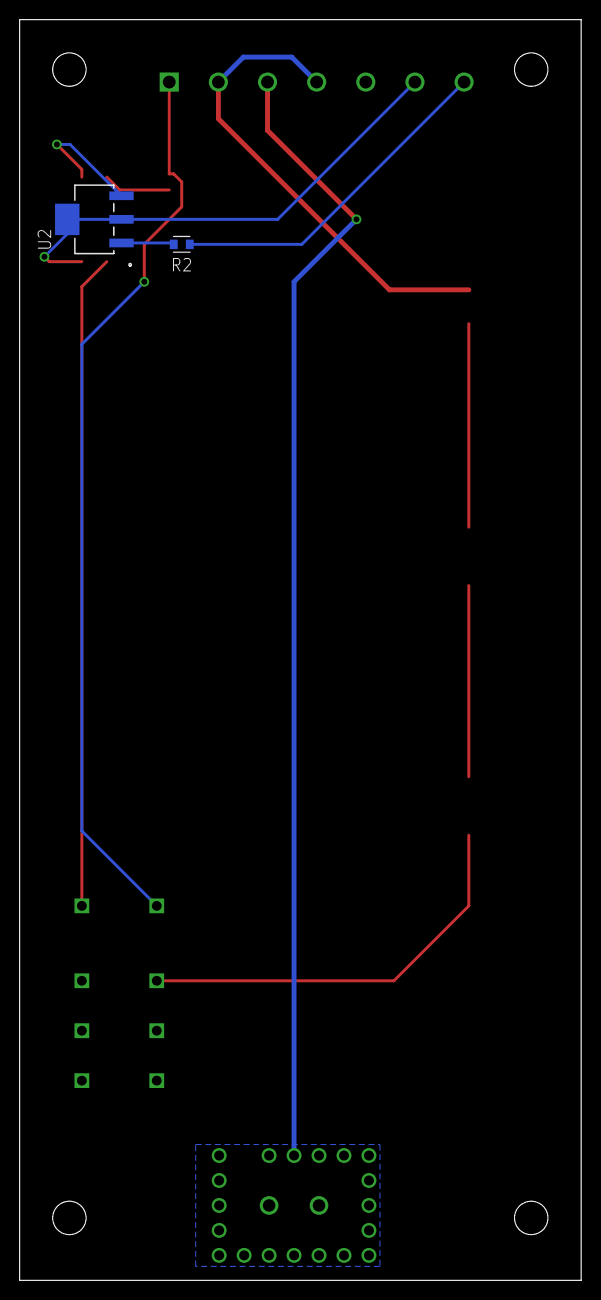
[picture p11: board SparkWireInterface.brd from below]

Board: 2 copper layers, 57.1 x 128.3 mm, 9 parts (2 on the bottom side), 11 nets.

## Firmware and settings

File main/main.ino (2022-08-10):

#include <SPI.h>
#include "PBTGraphics.hpp"

#define GLOBAL_TIME_LIMIT 8000 // Important define: Sets the time for a signal detection during auto test
#define PIM_TIME_LIMIT 8000
bool test_status = false;

void setup()
{
  Serial.begin(115200);
  initPins();
  initDisplay();
  drawMainMenu();
}

void loop()
{
  touchCheck();
  switch (getOption())
  {
  /* Case 1 is draw test menu and start test*/
  case 1:
    drawPreTestMenu(1);
    setActiveMenu(PRETEST);
    //  Function to setup fast ADC sampling
    ADCSetup();
    /* Reset test variables*/
    test_status = false; // Test is unsuccessful by default. Every test start, reset var
    /*
     * Start of PIM check
     */
    digitalWrite(POWERCTRL, HIGH);
    setSignalAlarm(waitUntilTriggered(PONSIG, PONTIMEOUT), POWERONOP);

    /* IMPORTANT
     * You must have an abort exception if the relay on the PBT board is not powered
     * this will cause a 24VAC path to draw high current through where it shouldn't,
     * notably in the left basket and right basket tests.
     */
    if (getSignalAlarm(POWERONOP))
    {
      digitalWrite(POWERCTRL, LOW);
      drawAbortMenu();
      setActiveMenu(ABORTMENU);
    }
    else
    {
      digitalWrite(THCALLCTRL, HIGH); // Call for heat

      /*
       * Check for blower power. Otherwise, wait.
       */
      drawPreTestMenu(2);
      unsigned long ct = millis(); // timer variables, current time
      unsigned long st = millis(); // start time
      while (ct - st <= BLPWRTIMEOUT)
      {
        ct = millis();
        if (sampleAndAverage(BLPWRSIG) == true)
        {
          setSignalAlarm(false, BLOWERPOWEROP);
          break;
        }
        else
        {
          setSignalAlarm(true, BLOWERPOWEROP);
        }
      }

      ct = st = millis();
      while (ct - st <= BLCTRLPWRTIMEOUT)
      {
        ct = millis();
        if (sampleAndAverage(BLCTRLPWRSIG) == true)
        {
          setSignalAlarm(false, BLOWERCONTROLOP);
          break;
        }
        else
        {
          setSignalAlarm(true, BLOWERCONTROLOP);
        }
      }

      ct = st = millis();
      while (ct - st <= BLPWRNEUTIMEOUT)
      {
        ct = millis();
        if (sampleAndAverage(BLPWRNEUSIG) == true)
        {
          setSignalAlarm(false, BLOWERPOWERNEUTRALOP);
          break;
        }
        else
        {
          setSignalAlarm(true, BLOWERPOWERNEUTRALOP);
        }
      }

      drawPreTestMenu(4);
      ct = st = millis();
      while (ct - st <= GASVALVETIMEOUT)
      {
        ct = millis();
        if (sampleAndAverage(GASVALVESIG) == true)
        {
          setSignalAlarm(false, GASVALVEOP);
          break;
        }
        else
        {
          setSignalAlarm(true, GASVALVEOP);
        }
      }

      drawPreTestMenu(3);
      ct = st = millis();
      int duty_met_sum = 0;
      while (ct - st <= PWMLOWTIMEOUT)
      {
        ct = millis();
        if (!dutyCheck(LDLB, LDHB))
        {
          duty_met_sum += 1;
        }
        if (duty_met_sum == 50)
        {
          setSignalAlarm(false, LOWDUTYCYCLEOP);
          break;
        }
        else
        {
          setSignalAlarm(true, LOWDUTYCYCLEOP);
        }
      }

      /* This is where spark detection would go */

      digitalWrite(SPD1, HIGH);
      drawPreTestMenu(6);
      ct = st = millis();
      duty_met_sum = 0;
      while (ct - st <= PWMHIGHTIMEOUT)
      {
        ct = millis();
        setSignalAlarm(false, ALARMOP); // Alarm's alarm is false by default
        if (!dutyCheck(HDLB, HDHB))
        {
          duty_met_sum += 1;
        }
        if (duty_met_sum == 50)
        {
          setSignalAlarm(false, HIGHDUTYCYCLEOP);
          break;
        }
        else
        {
          setSignalAlarm(true, HIGHDUTYCYCLEOP);
          if (sampleAndAverage(ALARMSIG) == true)
          {
            setSignalAlarm(true, ALARMOP); // Should break if alarm is raised during this time and indicate so
            break;
          }
        }
      }
      /*
       *
       * End of PIM check
       *
       */

      /*
       * Filter electronics check
       * If configuration is set to 1 (non-filter), then we should skip the filter system tests.
       * Otherwise, we'll execute the filter system tests.
       */
      if (getConfiguration() == 1)
      {
      }
      else
      {
        drawPreTestMenu(9);

        digitalWrite(PUMPCTRL, HIGH); // Enable relay to provide pump motor power

        ct = st = millis();
        while (ct - st <= PMPWRTIMEOUT)
        {
          ct = millis();
          if (sampleAndAverage(PMPWRSIG) == true)
          {
            setSignalAlarm(false, PUMPPOWEROP);
            break;
          }
          else
          {
            setSignalAlarm(true, PUMPPOWEROP);
          }
        }

        drawPreTestMenu(7);

        digitalWrite(SVALVECTRL, HIGH); // Should make that SVALVESIG signal active

        ct = st = millis();
        while (ct - st <= SVALVETIMEOUT)
        {
          ct = millis();
          if (sampleAndAverage(SVALVESIG) == false) // This is a little different. We're trying to see of it's inactive in this phase
          {
            setSignalAlarm(false, SOLENOIDVALVEOP);
            break;
          }
          else
          {
            setSignalAlarm(true, SOLENOIDVALVEOP);
          }
        }

        drawPreTestMenu(8);
        digitalWrite(SVALVECTRL, LOW);
        ct = st = millis();
        while (ct - st <= SVALVETIMEOUT)
        {
          ct = millis();
          if (sampleAndAverage(SVALVESIG) == true)
          {
            setSignalAlarm(false, SOLENOIDVALVEOP);
            break;
          }
          else
          {
            setSignalAlarm(true, SOLENOIDVALVEOP);
          }
        }
        /* Note that this solenoid check needs to happen after
         * the pump relay is activated, otherwise, it
         * will not be powered — even if the pump motor relay
         * is activated
         */
      }
      /*
       * Basket lift check
       */

      drawPreTestMenu(10);

      digitalWrite(BSKTCTRL, HIGH); // Activate basket control relay

      ct = st = millis();
      while (ct - st <= BSKTPWRTIMEOUT)
      {
        ct = millis();
        if (sampleAndAverage(BSKTPWRSIG) == true)
        {
          setSignalAlarm(false, BASKETPOWEROP);
          break;
        }
        else
        {
          setSignalAlarm(true, BASKETPOWEROP);
        }
      }

      drawPreTestMenu(11);

      ct = st = millis();
      while (ct - st <= LBSKTTIMEOUT)
      {
        ct = millis();
        if (sampleAndAverage(LBSKTSIG) == true)
        {
          setSignalAlarm(false, LEFTBASKETOP);
          break;
        }
        else
        {
          setSignalAlarm(true, LEFTBASKETOP);
        }
      }

      drawPreTestMenu(12);

      ct = st = millis();
      while (ct - st <= RBSKTTIMEOUT)
      {
        ct = millis();
        if (sampleAndAverage(RBSKTSIG) == true)
        {
          setSignalAlarm(false, RIGHTBASKETOP);
          break;
        }
        else
        {
          setSignalAlarm(true, RIGHTBASKETOP);
        }
      }

      /*
       * End of basket lift check
       */
      switch (getConfiguration())
      {
      case 0:
        if (getSignalAlarm(HIGHDUTYCYCLEOP) || getSignalAlarm(LOWDUTYCYCLEOP) || getSignalAlarm(ALARMOP) || getSignalAlarm(BASKETPOWEROP) || getSignalAlarm(BLOWERPOWERNEUTRALOP) || getSignalAlarm(BLOWERCONTROLOP) || getSignalAlarm(RIGHTBASKETOP) || getSignalAlarm(SOLENOIDVALVEOP) || getSignalAlarm(PUMPPOWEROP) || getSignalAlarm(GASVALVEOP) || getSignalAlarm(BLOWERPOWEROP) || getSignalAlarm(POWERONOP))
        {
          test_status = false;
        }
        else
        {
          test_status = true;
        }
        break;
      case 1:
        if (getSignalAlarm(HIGHDUTYCYCLEOP) || getSignalAlarm(LOWDUTYCYCLEOP) || getSignalAlarm(ALARMOP) || getSignalAlarm(BASKETPOWEROP) || getSignalAlarm(BLOWERPOWERNEUTRALOP) || getSignalAlarm(BLOWERCONTROLOP) || getSignalAlarm(RIGHTBASKETOP) || getSignalAlarm(GASVALVEOP) || getSignalAlarm(BLOWERPOWEROP) || getSignalAlarm(POWERONOP))
        {
          test_status = false;
        }
        else
        {
          test_status = true;
        }
        break;
      default:
        if (getSignalAlarm(HIGHDUTYCYCLEOP) || getSignalAlarm(LOWDUTYCYCLEOP) || getSignalAlarm(ALARMOP) || getSignalAlarm(BASKETPOWEROP) || getSignalAlarm(BLOWERPOWERNEUTRALOP) || getSignalAlarm(BLOWERCONTROLOP) || getSignalAlarm(RIGHTBASKETOP) || getSignalAlarm(SOLENOIDVALVEOP) || getSignalAlarm(PUMPPOWEROP) || getSignalAlarm(GASVALVEOP) || getSignalAlarm(BLOWERPOWEROP) || getSignalAlarm(POWERONOP))
        {
          test_status = false;
        }
        else
        {
          test_status = true;
        }
        break;
      }
      /* Disable GPIO */
      digitalWrite(POWERCTRL, LOW);
      digitalWrite(SPD1, LOW);
      digitalWrite(THCALLCTRL, LOW);
      digitalWrite(SVALVECTRL, LOW);
      digitalWrite(PUMPCTRL, LOW);
      digitalWrite(BSKTCTRL, LOW);

      /* Proceed to next menu */
      drawPostTestMenu(test_status);
      setActiveMenu(POSTTEST);
    }
    break;
  /* Case 2 will bring you back to the main menu and reset necessary variables */
  case 2:
    drawMainMenu();
    setActiveMenu(MAINMENU);
    break;
  /* Case 3 happens when the results button is pressed. It will set up the results screen. */
  case 3:
    drawResultsMenu();
    setActiveMenu(RESULTS);
    break;
  /* Case 4 happens when the PIM info button is pressed on the results screen */
  case 4:
    drawPIMInfoMenu();
    setActiveMenu(PIMINFO);
    break;
  case 5:
    drawPumpInfoMenu();
    setActiveMenu(PUMPINFO);
    break;
  case 6:
    drawBasketInfoMenu();
    setActiveMenu(BSKTINFO);
    break;
  case 8:
    drawConfigurationMenu();
    setActiveMenu(CONFIG);
    break;
  case 9:
    drawDebugMenu();
    setActiveMenu(DEBUG);
    break;
  case 10:
    drawLockMenu();
    setActiveMenu(LOCK);
    break;
  }
}

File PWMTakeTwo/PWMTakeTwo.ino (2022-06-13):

#define IN1 54
#define MAXSAMPLES 1000
#include <avr/pgmspace.h>

#define FASTADC 1
// defines for setting and clearing register bits
#ifndef cbi
#define cbi(sfr, bit) (_SFR_BYTE(sfr) &= ~_BV(bit))
#endif
#ifndef sbi
#define sbi(sfr, bit) (_SFR_BYTE(sfr) |= _BV(bit))
#endif

const unsigned long samplePeriod = .0001; // Sampling rate of 1 millisecond. May require adjusting depending on the highest frequency component of the PWM.

void delaySamplePeriod() {
  static unsigned long lastTime = 0;
  if (millis() - lastTime > samplePeriod) {
    lastTime = millis();
  } else {
    while (millis() - lastTime < samplePeriod) {
      //wait
      yield();
    }
    lastTime += samplePeriod;
  }
}

void printXInPMemContents(int *xAddr){
  Serial.println("Printing results");
  for(int i = 0; i < MAXSAMPLES; i++){
    Serial.println(xAddr[i]);
  }
}

void printXContents(int xAddr[]){
  Serial.println("Printing results");
  for(int i = 0; i < MAXSAMPLES; i++){
    Serial.println(xAddr[i]);
  }
}


void halt(){
  while(true){
  }
}

void pwmMeasure(int x_in[]){
  for(int i = 0; i < MAXSAMPLES; i++){
    delaySamplePeriod();
    x_in[i] = analogRead(IN1);
  }
}

double calcDutyCycle(int x_in[]){
  // Find the max value
  static int max_val = 0;
  for(int i = 0; i < MAXSAMPLES; i++){
    if(x_in[i] > max_val){
      max_val = x_in[i];
    }
  }
  // Find the min value
  static int min_val = 1025; // 1024 is the max analog read value
  for(int i = 0; i < MAXSAMPLES; i++){
    if(x_in[i] < min_val){
      min_val = x_in[i];
    }
  }

  static const double coef = 0.01*(max_val-min_val); // !! Smoothing coefficient meant to reduce the effect of noisy signal. Really important for real signals !!
                                                   // Adjust the numerical constant (0.9, 0.75, 0.01, etc...) to increase the leniency of the variation.
 // Find the low time
  static int dtimer = 0;
  static double low_time = 0;
  static bool dtimer_start = false;
  static bool measure_start = false;
  for(int i = 0; i < MAXSAMPLES; i++){
    if(measure_start == false){
      if(x_in[i] != min_val){
        measure_start = true;
      }
    }
    if(measure_start == true){
      if (x_in[i] == min_val && dtimer_start == false){
        dtimer_start = true;
        dtimer+=1;
      }
      if (dtimer_start == true && x_in[i] <= min_val+coef){
        dtimer+=1;
      }
      else if (dtimer_start == true && x_in[i] >= min_val+coef){
        low_time = dtimer;
        break;
      }
    }
  }
  // Find the high time
  dtimer = 0;
  static double high_time = 0;
  dtimer_start = false;
  measure_start = false;
  for(int i = 0; i < MAXSAMPLES; i++){
    if(measure_start == false){
      if(x_in[i] != max_val){
        measure_start = true;
      }
    }
    if(measure_start == true){
      if (x_in[i] == max_val && dtimer_start == false){
        dtimer_start = true;
      }
      if (dtimer_start == true && x_in[i] >= max_val - coef){
        dtimer+=1;
      }
      else if (dtimer_start == true && x_in[i] <= max_val-coef){
        high_time = dtimer;
        break;
      }
    }
  }
  // Find rise time
  dtimer = 0;
  static double rise_time = 0;
  dtimer_start = false;
  measure_start = false;
  for(int i = 0; i < MAXSAMPLES; i++){
    if(measure_start == false){
      if(x_in[i] == min_val){
        measure_start = true;
      }
    }
    if(measure_start == true){
      if (x_in[i] != min_val && dtimer_start == false){
        dtimer_start = true;
      }
      if (dtimer_start == true && x_in[i] <= max_val - coef){
        dtimer+=1;
      }
      else if (dtimer_start == true && x_in[i] >= max_val - coef){
        rise_time = dtimer;
        break;
      }
    }
  }
  // Find fall time
  dtimer = 0;
  static double fall_time = 0;
  dtimer_start = false;
  measure_start = false;
  for(int i = 0; i < MAXSAMPLES; i++){
    if(measure_start == false){
      if(x_in[i] == max_val){
        measure_start = true;
      }
    }
    if(measure_start == true){
      if (x_in[i] != max_val && dtimer_start == false){
        dtimer_start = true;
      }
      if (dtimer_start == true && x_in[i] >= min_val + coef){
        dtimer+=1;
      }
      else if (dtimer_start == true && x_in[i] <= min_val + coef){
        fall_time = dtimer;
        break;
      }
    }
  }
  double period = (rise_time/2)+(fall_time/2)+high_time+low_time;
  double duty_cycle = high_time/period;
  return duty_cycle;
}

void setup() {
  pinMode(IN1, INPUT);
  Serial.begin(115200);
}

void loop() {
  #if FASTADC
  // set prescale to 16
  sbi(ADCSRA,ADPS2) ;
  cbi(ADCSRA,ADPS1) ;
  cbi(ADCSRA,ADPS0) ;
  #endif
  int* x = new int[MAXSAMPLES];
  Serial.println("Starting");
  pwmMeasure(x);
  /*
  int x_len = sizeof(x)/sizeof(x[0]);
  void *x_p_void = memcpy_P(0, x, x_len);
  int *x_p = (int*)x_p_void;
  printXInPMemContents(x_p);
  */
  printXContents(x);
  //double duty = calcDutyCycle(x);
  //Serial.println(duty);
  Serial.println("Halting");
  halt();
}

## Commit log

2022-06-09 Update pwmReadStarter.ino
    Removed linked lists in favor of arrays stored in memory
2022-06-10 Functioning sampling and duty cycle calculation. For whatever reason bugged when other arduino outputs higher duty cycles
    [PWMTakeTwo.ino, pwmOUT.ino]
2022-06-15 added visualizer
    [ADCVisual.xlsx]
2022-06-17 removed excel file
    [ADCVisual.xlsx]
2022-06-17 Added ADC test
2022-06-30 Adjusted menu, added results menu
    [BOM_AutoPBT.xlsx]
2022-06-30 Can switch between main, pre, post , and results
2022-06-30 Added ordering info
    [BOM.xlsx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]
2022-06-30 filter test stuff
2022-07-05 Adjusting pwm testing tools
2022-07-05 Fixed pwmCheck
2022-07-20 Added revision for Auto Power Box Tester
    [BOM.xlsx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]
2022-07-20 Previous commit but actually
    [AutoPBT.brd, AutoPBT.sch, BOM.xlsx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]
2022-07-21 Updated readme and ordering info
    [AutoPBT.brd, AutoPBT.sch, BOM.xlsx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]
2022-07-25 Cool downs for buttons in debug
2022-07-26 text now stays after button press
2022-07-26 Power on status added to debug and non touch event
2022-07-26 Debug functional. Need to add power lockout
2022-07-27 Power lockout implemented into manual
2022-07-27 Adding flame sense button (only visual init)
2022-07-27 Added flame sense button to manual control
2022-07-28 removed recom, adjusted results for non filter
2022-07-28 Adjusted results button location
2022-08-03 Added sample and average functionality
2022-08-03 Functioning sampleAndAverage
2022-08-05 Readme updates
    [AutoPBT.brd, AutoPBT.sch, BOM.xlsx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]
2022-08-05 reorganization part 10 or whatever
    [BOM.xlsx, PnP_AutoPBT v287_back.csv, PnP_AutoPBT v287_front.csv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]
2022-08-05 changed manual test to update pwm correctly
2022-08-09 actually fixed auto test
    [main.ino]

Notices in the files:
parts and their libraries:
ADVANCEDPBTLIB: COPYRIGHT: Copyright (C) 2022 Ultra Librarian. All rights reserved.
